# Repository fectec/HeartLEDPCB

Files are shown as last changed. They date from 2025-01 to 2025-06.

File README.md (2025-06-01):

# Heart LED PCB

<p align="justify">A collection of <b>Valentine's Day-themed PCB designs</b> featuring LED animations in the shape of a heart. Perfect for pendants or keyrings!</p>

## Main Branch

<p align="justify">The main branch features a design built around the <b>ICM7555</b> timer IC, configured in astable operation mode. The timer output drives a <b>CD4017B</b> decade counter, which sequences through LEDs to create an animated pattern. Power is supplied by a <b>CR2032</b> 3 V battery through a <b>TPS6122</b> boost converter.</p>

<p align="center">
  Main PCB
</p>

<p align="center">
  Main Front
</p>

<p align="center">
  Main Back
</p>

### Components Overview

#### ICM7555IBAZ-T

<p align="justify">The ICM7555 is a CMOS RC timer that provides significantly improved performance over the standard SE/NE 555/556 and 355 timers. It is a direct replacement for these devices in most applications. Enhanced features include low supply current (<i>60 μA</i>), a wide operating supply voltage range (<i>2V to 18V</i>), higher frequency performance, and no requirement to decouple the Control Voltage pin for stable operation.</p> 

<p align="justify">Although the ICM7555 itself consumes very little current, the total system supply current can increase unless high-impedance timing components are used. To address this, a high value for R and a low value for C were selected.</p> 

<p align="justify">The frequency of the astable operation is determined by the formula:</p> 

<div align="center">
	
$`f=\frac{1}{RC}`$

</div>

<p align="justify">To achieve a period of approximately one second, R was set to <i>100 kΩ</i> and C to <i>4.7 μF</i>.</p> 

<p align="center">
  ICM7555 Astable Operation
</p>

#### CD4017BM96

<p align="justify">The CD4017B is a decade counter with 10 decoded outputs. Each output remains high for the duration of one full clock cycle, sequentially cycling through the outputs with each clock pulse. It operates over a wide supply voltage range of <i>3V to 18V</i>, making it compatible with various applications.</p>

#### TPS61222DCKR

<p align="justify">The TPS6122x family devices provide a power-supply solution for products powered by single-cell, two-cell, or three-cell alkaline, NiCd, or NiMH batteries, or a single-cell Li-Ion or Li-polymer battery. They offer up to 95% efficiency under typical operating conditions.</p>

<p align="justify">In this design, the specific application of the device is a fixed output voltage supply of <i>5 V at up to 60 mA</i>. The TPS61222 DC/DC converter is suitable for systems powered by a total typical input voltage between 0.7 V and 5.5 V.</p>

<p align="justify">In the fixed-voltage version, the output is set by an internal resistor divider. To ensure proper operation, a suitable inductor must be connected between pin VIN and pin L. Inductor values of <i>4.7 μH</i> provide good performance across the full input and output voltage range. Using inductor values below 2.2 μH is not recommended.</p>

<p align="justify">An input capacitor with a value of at least <i>10 μF</i> is recommended to improve the transient behavior of the regulator and reduce EMI in the total power supply circuit. A ceramic capacitor placed as close as possible to the VIN and GND pins of the IC is advised.</p>

<p align="justify">For the output capacitor (C2), small ceramic capacitors are recommended, placed as close as possible to the VOUT and GND pins of the IC. A minimum capacitance value of 4.7 μF should be used; <i>10 μF</i> is preferred.</p>

<p align="center">
  TPS61222DCKR Application Circuit For Fixed Output Voltage Option
</p>

### BOM & Schematic Diagram

| Component | Value/Model | Qty | LCSC # | Notes |
|---|---|-----|---|---|
| BT1 | Keystone 1060 | 1 | C5370859 | CR2032 holder |
| C1 | 4.7 µF | 1 | C1705 | ICM7555 capacitor | 
| C2, C3 | 10 µF | 2 | C1691 | TPS61222 Input/output caps |
| L1 | 4.7 µH | 1 | C576538 | LQH3NPN series |
| R1 | 100 kΩ | 1 | C15458 | Timer RC network |
| R2 | 10 kΩ | 1 | C25531 | Timer RC network |
| R3-R12 | 3.3 kΩ | 10  | C25936 | LED current limit |
| U1 | ICM7555IBAZ-T | 1 | C357816 | CMOS timer |
| U2 | CD4017BM96 | 1 | C11349 | Decade counter |
| U3 | TPS61222DCKR | 1 | C116461 | Boost converter |
| U4 | HX SS12F44G4 | 1 | C5149844 | Power switch |
| TP1-TP3 | 1.0 mm | 3 | - | Test points |

<p align="center">
  Main HeartLED PCB Schematic Diagram
</p>

## HT7750A Branch

<p align="justify">In this branch, the TPS61222DCKR converter is replaced by the <b>HT7750A</b>. The HT77XXA series is a family of step-up DC/DC converters known for their high efficiency and low ripple. These converters feature an extremely low start-up voltage and high output voltage accuracy. They require only three external components to provide a fixed output voltage of 2.7 V, 3.0 V, 3.3 V, or <i>5.0 V</i>.</p>

<p align="center">
  HT7750A Application Circuit For Fixed Output Voltage Option
</p>

<p align="center">
  HT7750A PCB
</p>

<p align="center">
  HT7750A Front
</p>

<p align="center">
  HT7750A Back
</p>

### BOM & Schematic Diagram

| Component | Value/Model | Qty | LCSC # | Notes |
|---|---|-----|---|---|
| BT1 | Keystone 1060 | 1 | C5370859 | CR2032 holder |
| C1 | 4.7 µF | 1 | C1705 | ICM7555 capacitor | 
| C2 | 47 µF (Tantalum) | 1 | C7190 | HT7750A input capacitor |
| C3 | 22 µF (Tantalum) | 1 | C7183 | HT7750A output capacitor |
| L1 | 47-100 µH | 1 | C1034 | HT7750A inductor |
| S1 | 1N5817 | 1 | C727113 | HT7750A schottky diode |
| R1 | 100 kΩ | 1 | C15458 | Timer RC network |
| R2 | 10 kΩ | 1 | C25531 | Timer RC network |
| R3-R12 | 3.3 kΩ | 10  | C25936 | LED current limit |
| U1 | ICM7555IBAZ-T | 1 | C357816 | CMOS timer |
| U2 | CD4017BM96 | 1 | C11349 | Decade counter |
| U3 | HT7750A | 1 | C25988 | Boost converter |
| U4 | HX SS12F44G4 | 1 | C5149844 | Power switch |
| TP1-TP3 | 1.0 mm | 3 | - | Test points |

<p align="center">
  HT7750A HeartLED PCB Schematic Diagram
</p>

## MCU Branch

<p align="justify">This branch replaces the timer and decade counter with an <b>ATtiny816</b> microcontroller. The ATtiny816 is a member of the tinyAVR® 1-series family featuring advanced analog features and core independent peripherals. This design allows for more sophisticated LED control and animations through programmable patterns.</p>

<p align="justify">Programming is accomplished via the Unified Program and Debug Interface (<i>UPDI</i>), a one-wire interface for external programming and debugging. The circuit incorporates a tactile button connected to a GPIO pin for user interaction.</p>

<p align="center">
  MCU PCB
</p>

<p align="center">
  MCU Front
</p>

<p align="center">
  MCU Back
</p>

### BOM & Schematic Diagram

| Component | Value/Model | Qty | LCSC # | Notes |
|---|---|-----|---|---|
| BT1 | CR2032-BS-6-1 | 1 | C70377 | CR2032 holder |
| C1 | 100 nF | 2 | C301918 | MCU decoupling capacitors |
| C2 | 100 nF | 2 | C301918 | Button debounce capacitor |
| D1 | LED (Blue) | 1 | C7496819 | Status LED |
| D2-D10 | LED (Red) | 9 | C7496820 | Animation LEDs |
| J1 | 1x03 2.54 mm | 1 | - | UPDI programming header |
| R1-R11 | 1 kΩ | 11  | C25543 | LED current limit |
| SW1 | TS-1187A-B-A-B | 1 | C318884 | Tactile switch |
| U1 | HX SS12F44G4 | 1 | C5149844 | Power switch |
| U2 | ATTINY816-MN | 1 | C617908 | Main MCU |
| TP1 | 1.5 mm | 1 | - | Test point |

<p align="center">
  MCU HeartLED PCB Schematic Diagram
</p>

## Simple NE555 Branch

<p align="justify">Finally, this branch replaces the ICM7555 timer IC with a conventional <b>NE555</b>, offering a cost-effective alternative that requires only one SMD component - the IC itself. This design imitates a popular DIY kit, where the NE555 generates a <i>1 Hz signal</i> at pin 3, alternating between high and low levels. When pin 3 is low, the upper row of LEDs illuminates, and when high, the bottom row lights up instead, creating an appealing visual effect.</p>

<p align="justify">While the circuit can operate with a CR2032 3V battery, one LED row will appear dimmer due to the NE555's minimum voltage requirements. For optimal brightness across both rows, a 5V power supply connector can be soldered to the board as an alternative power source.</p>

<p align="center">
  NE555 PCB
</p>

<p align="center">
  NE555 Front
</p>

<p align="center">
  NE555 Back
</p>

<p align="center">
  NE555 PCB IRL
</p>

### BOM & Schematic Diagram

| Component | Value/Model | Qty | Notes |
|---|---|-----|---|
| U1 | NE555DR | 1 | RC Timer |
| U2 | 1066 | 1 | CR2032 holder |
| SW1 | SS12D00G3 | 1 | Power switch |
| D1-D10 | LED 3.00 mm | 10  | LEDs |
| R1-R10 | 1 kΩ 6.3 x 2.5 x 7.62 mm | 10  | LED current limit |
| R11-R12 | 10 kΩ 6.3 x 2.5 x 7.62 mm | 2 | Timer RC network |
| C1 | 47 µF 5.00 x 7.00 x 2.00 mm | 1 | NE555 capacitor |
| J1 | 1x02 2.54 mm | 1 | Power supply header |

<p align="center">
  NE555 HeartLED PCB Schematic Diagram
</p>

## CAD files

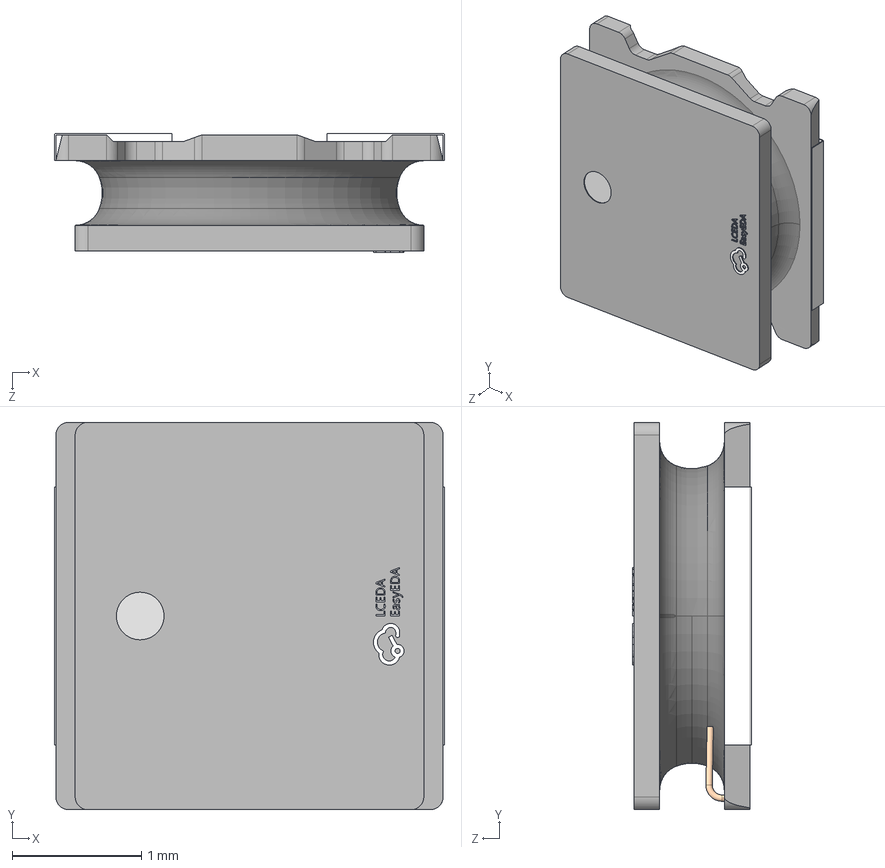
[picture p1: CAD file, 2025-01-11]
HeartLED_PCB/COMPONENTS/3D/LQH3NPN4R7MMEL.step
3.02 x 3.00 x 0.92 mm

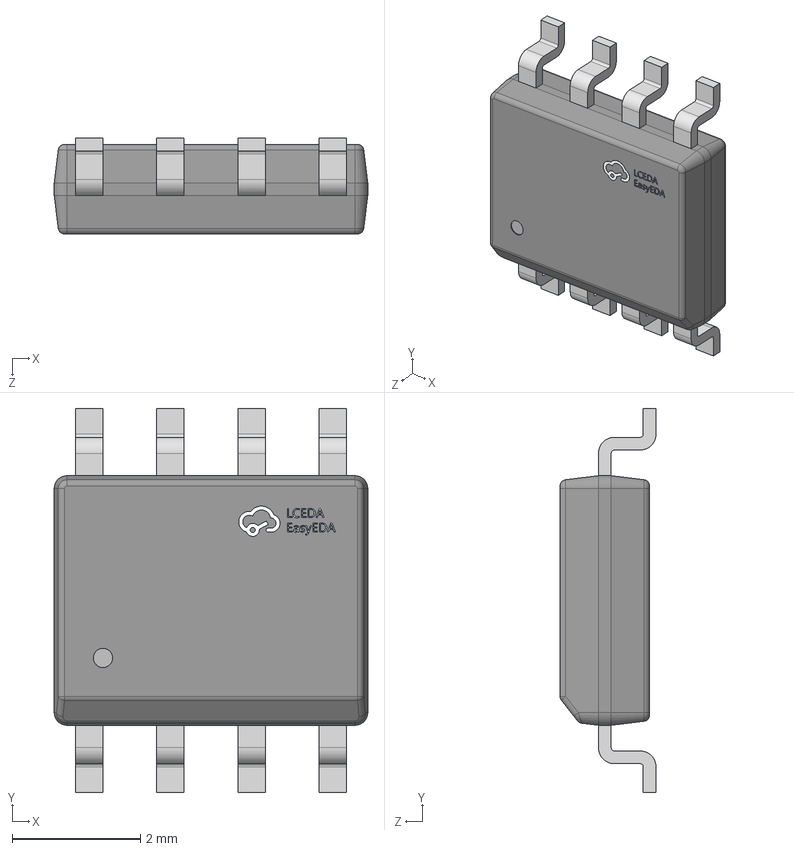
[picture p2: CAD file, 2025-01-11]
HeartLED_PCB/COMPONENTS/3D/ICM7555IBAZ-T.step
4.90 x 6.00 x 1.50 mm

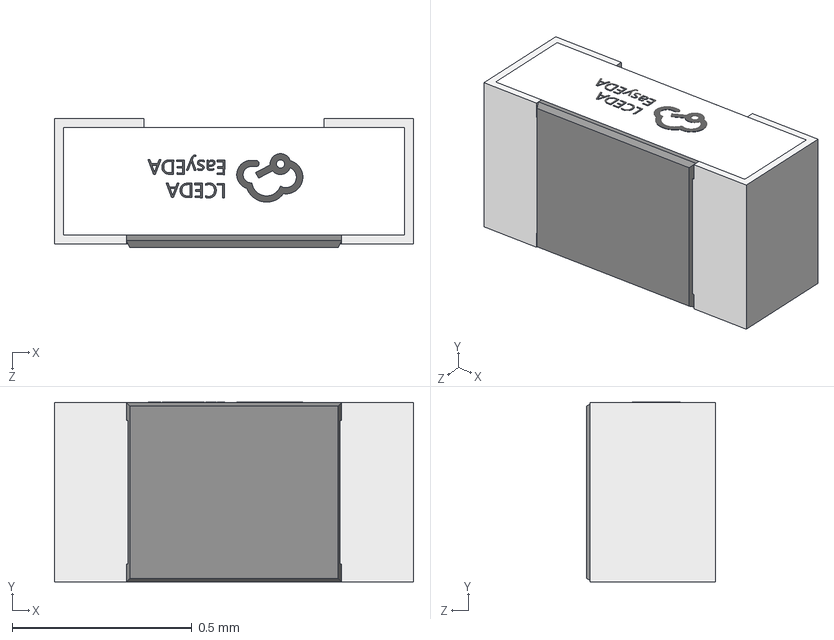
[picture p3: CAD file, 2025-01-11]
HeartLED_PCB/COMPONENTS/3D/0402WGJ0103TCE.step
1.00 x 0.501 x 0.36 mm

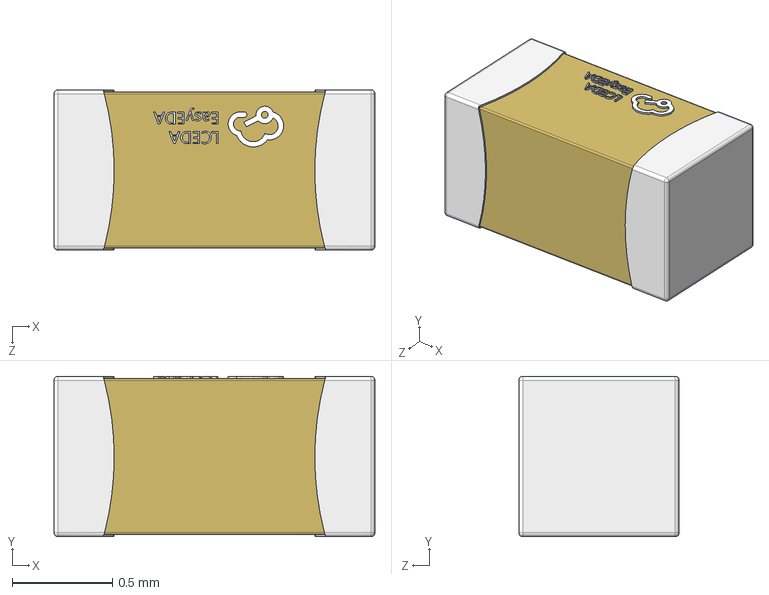
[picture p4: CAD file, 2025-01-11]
HeartLED_PCB/COMPONENTS/3D/CL10A106MQ8NNNC.step
1.60 x 0.8 x 0.8 mm

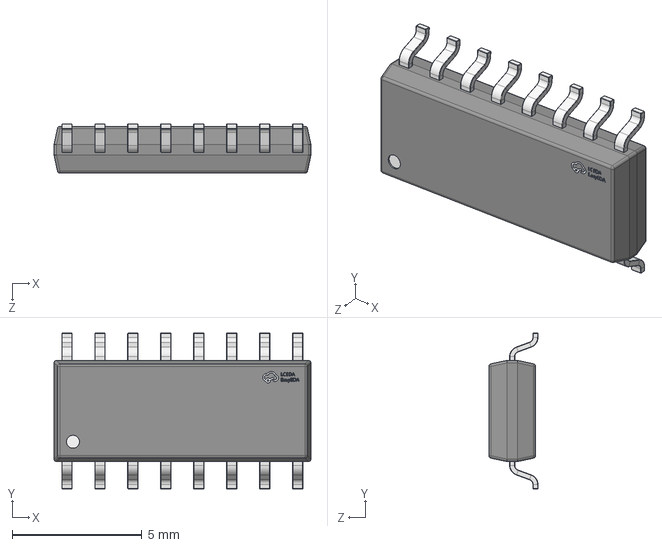
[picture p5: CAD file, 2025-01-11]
HeartLED_PCB/COMPONENTS/3D/CD4017BM96.step
9.90 x 6.01 x 1.90 mm

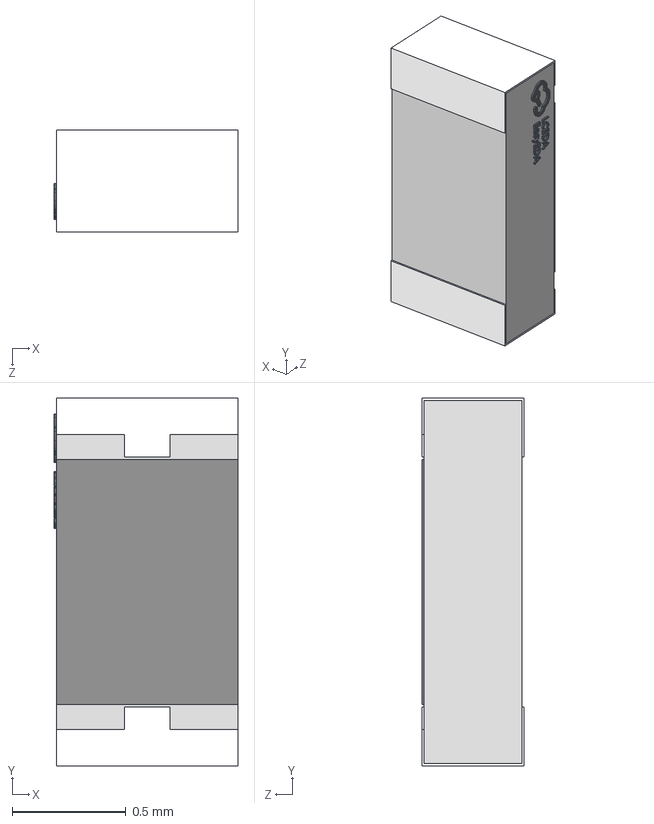
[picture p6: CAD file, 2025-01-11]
HeartLED_PCB/COMPONENTS/3D/0603WAJ0104T5E.step
0.81 x 1.62 x 0.45 mm

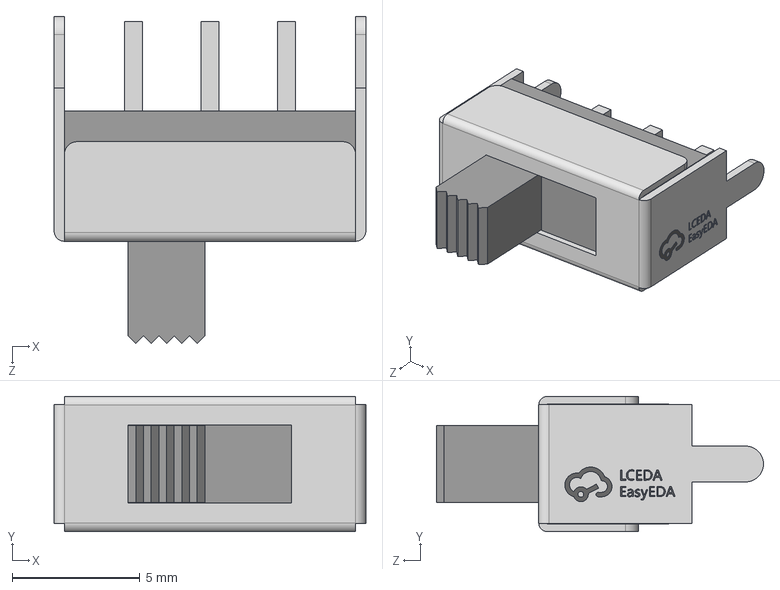
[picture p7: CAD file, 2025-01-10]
HeartLED_PCB/COMPONENTS/3D/HX SS12F44G4.step
12.2 x 5.30 x 12.8 mm

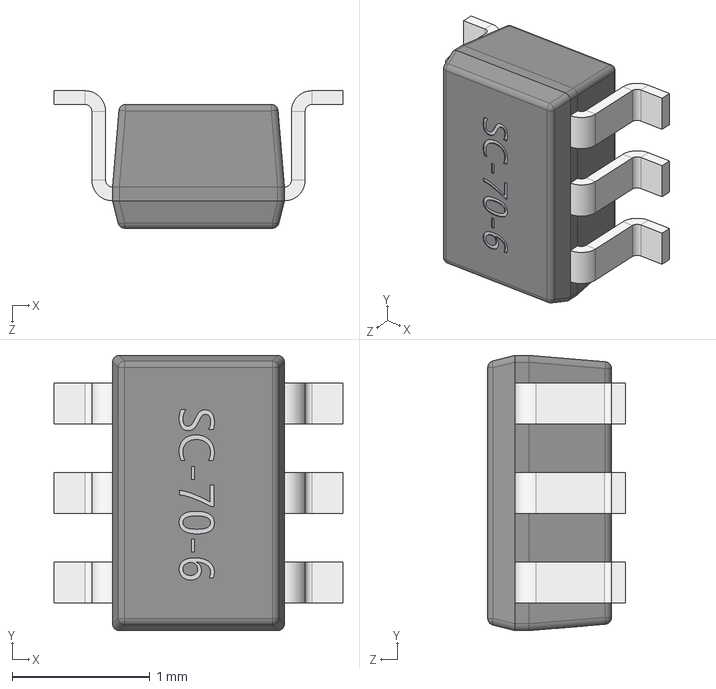
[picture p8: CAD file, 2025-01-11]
HeartLED_PCB/COMPONENTS/3D/TPS61222DCKR.step
2.10 x 2.00 x 1.00 mm

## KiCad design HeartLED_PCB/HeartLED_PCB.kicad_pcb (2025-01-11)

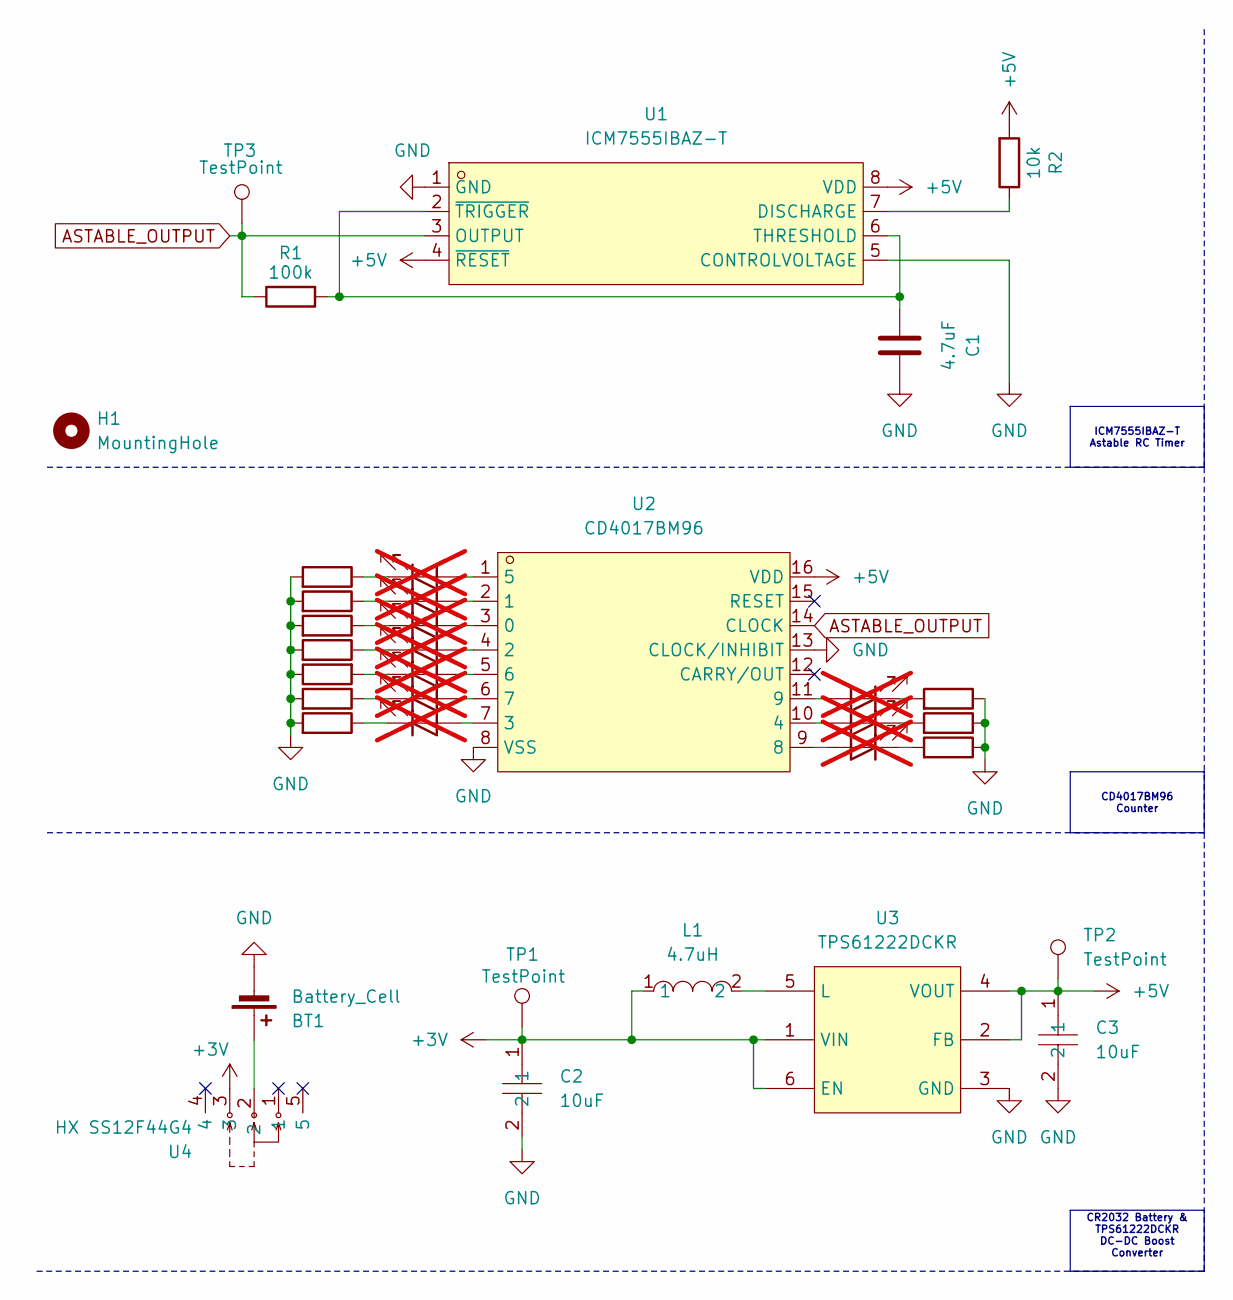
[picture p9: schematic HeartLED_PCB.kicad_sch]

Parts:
BT1: Battery_Cell; BatteryHolder_Keystone_1060_1x2032; LCSC C5370859
C1: 4.7uF; CL10A475KP8NNNC; LCSC C1705
C2, C3: 10uF; CL10A106MQ8NNNC; LCSC C1691
D1, D2, D3, D4, D5, D6, D7, D8, D9, D10: LED; LED_D3.0mm; not fitted
H1: MountingHole; MountingHole_2.1mm
L1: 4.7uH; LQH3NPN4R7MMEL; LCSC C576538
R1: 100k; 0603WAJ0104T5E; LCSC C15458
R2: 10k; 0402WGJ0103TCE; LCSC C25531
R3, R4, R5, R6, R7, R8, R9, R10, R11, R12: 3.3k; 0402WGJ0332TCE; LCSC C25936
TP1, TP2, TP3: TestPoint; TestPoint_Pad_D1.0mm
U1: ICM7555IBAZ-T; LCSC C357816
U2: CD4017BM96; LCSC C11349
U3: TPS61222DCKR; LCSC C116461
U4: HX SS12F44G4; LCSC C5149844

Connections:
+3V: C2.1, L1.1, TP1.1, U3.1 (VIN), U3.6 (EN), U4.3
+5V: C3.1, R2.2, TP2.1, U1.4 (~RESET), U1.8 (VDD), U2.16 (VDD), U3.2 (FB), U3.4 (VOUT)
ASTABLE_OUTPUT: R1.1, TP3.1, U1.3 (OUTPUT), U2.14 (CLOCK)
GND: BT1.2 (-), C1.2, C2.2, C3.2, R3.2, R4.2, R5.2, R6.2, R7.1, R8.2, R9.2, R10.1, R11.1, R12.1, U1.1 (GND), U1.5 (CONTROLVOLTAGE), U2.8 (VSS), U2.13 (CLOCK/INHIBIT), U3.3 (GND)
unnamed: BT1.1 (+), U4.2
unnamed: D1.2 (A), U2.1 (5)
unnamed: D1.1 (K), R3.1
unnamed: D2.2 (A), U2.2 (1)
unnamed: D2.1 (K), R4.1
unnamed: D3.2 (A), U2.3 (0)
unnamed: D3.1 (K), R5.1
unnamed: D4.2 (A), U2.4 (2)
unnamed: D4.1 (K), R6.1
unnamed: D5.2 (A), U2.5 (6)
unnamed: D5.1 (K), R7.2
unnamed: D6.2 (A), U2.6 (7)
unnamed: D6.1 (K), R8.1
unnamed: D7.2 (A), U2.7 (3)
unnamed: D7.1 (K), R9.1
unnamed: D8.2 (A), U2.9 (8)
unnamed: D8.1 (K), R10.2
unnamed: D9.2 (A), U2.10 (4)
unnamed: D9.1 (K), R11.2
unnamed: D10.2 (A), U2.11 (9)
unnamed: D10.1 (K), R12.2
unnamed: R2.1, U1.7 (DISCHARGE)
unnamed: C1.1, R1.2, U1.2 (~TRIGGER), U1.6 (THRESHOLD)
unnamed: L1.2, U3.5 (L)

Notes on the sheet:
CR2032 Battery & TPS61222DCKR DC-DC Boost Converter
CD4017BM96 Counter
ICM7555IBAZ-T Astable RC Timer

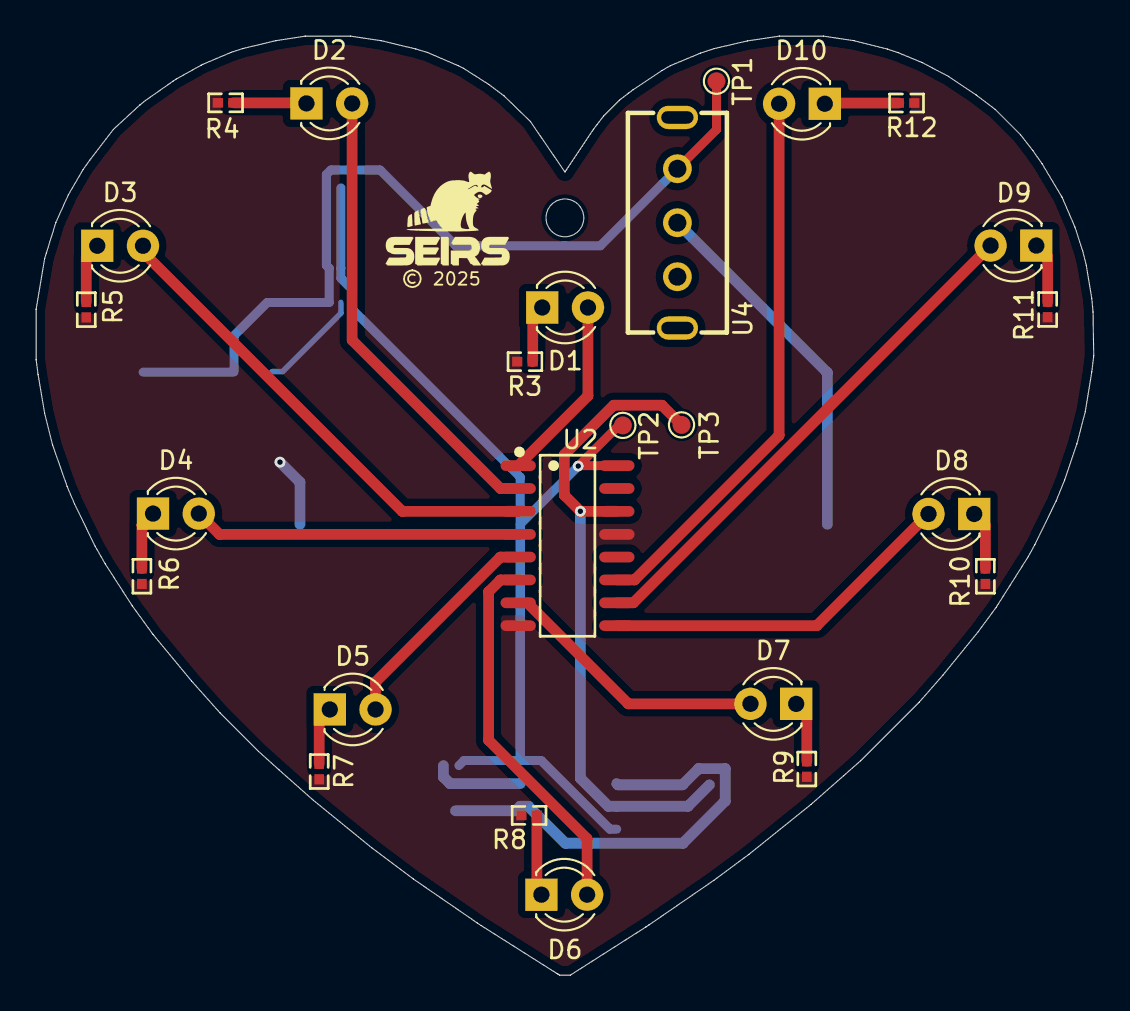
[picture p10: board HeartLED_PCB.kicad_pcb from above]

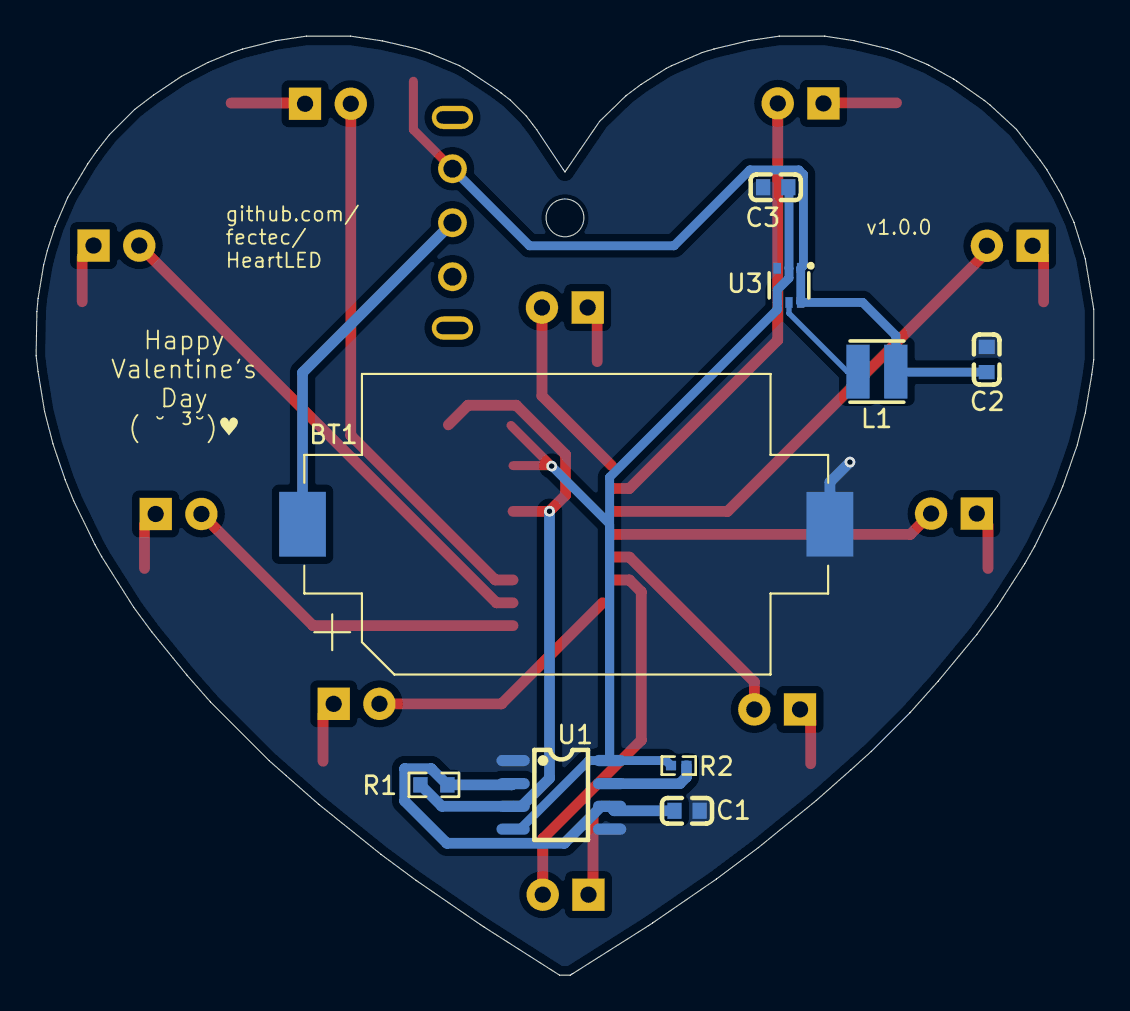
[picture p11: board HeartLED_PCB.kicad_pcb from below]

Board: 2 copper layers, 58.8 x 52.2 mm, 35 parts (9 on the bottom side), 28 nets.

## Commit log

2025-01-10 Routed PCB
    [HeartLEDChaser_PCB.kicad_pcb, HeartLEDChaser_PCB.kicad_sch]
2025-01-10 Added logos
    [HeartLEDChaser_PCB.kicad_pcb]
2025-01-10 Improved layout & routing
    [HeartLEDChaser_PCB.kicad_pcb, HeartLEDChaser_PCB.kicad_sch]
2025-01-10 Corrected capacitor references
    [HeartLEDChaser_PCB.kicad_pcb, HeartLEDChaser_PCB.kicad_sch]
2025-01-10 Renamed project
    [CD4017BM.STEP, HXSS12F44G4.step, HeartLED_PCB.kicad_pcb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]
2025-01-11 Added LCSC and 3D models
    [0402WGJ0103TCE.step, 0402WGJ0332TCE.step, 0603WAJ0104T5E.step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]
2025-01-11 Changed inductor
    [HeartLED_PCB.kicad_pcb, HeartLED_PCB.kicad_sch, SMNR5040-470MT.step]
2025-01-11 Added TestPoints and corrected track width for power nets
    [HeartLED_PCB.kicad_pcb, HeartLED_PCB.kicad_sch]
2025-01-11 Changed Timer and Counter models
    [C11349.step, HeartLED_PCB.kicad_pcb, HeartLED_PCB.kicad_sch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]
2025-01-11 Added some 3D models
    [CD4017BM96.step, HeartLED_PCB.kicad_pcb]
2025-01-11 Changed DC-DC Boost Converter
    [1N5817.step, CL10A106MQ8NNNC.step, HT7750A.step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]

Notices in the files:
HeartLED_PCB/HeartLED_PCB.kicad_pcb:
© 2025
